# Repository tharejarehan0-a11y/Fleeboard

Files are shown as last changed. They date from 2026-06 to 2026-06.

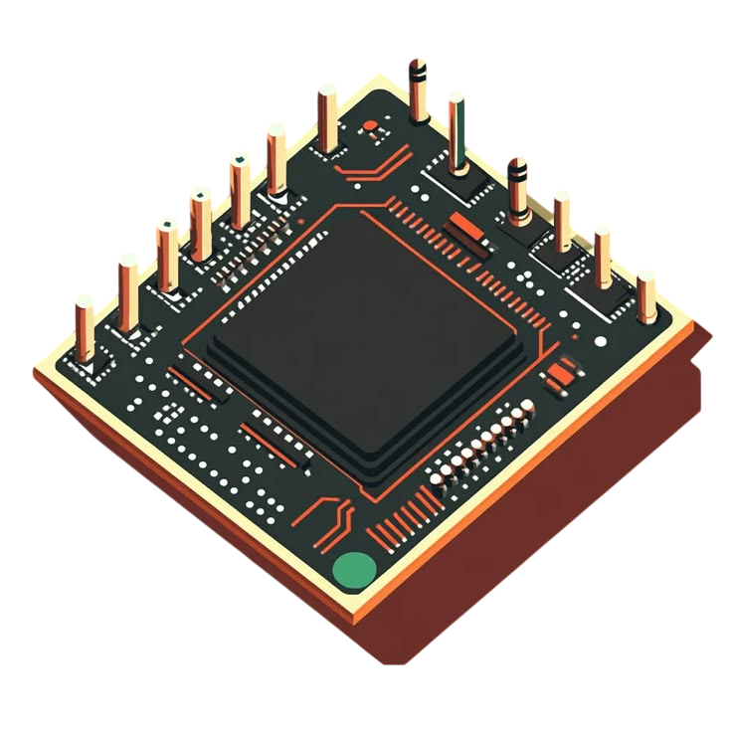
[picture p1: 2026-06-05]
Media/soc-Photoroom.png

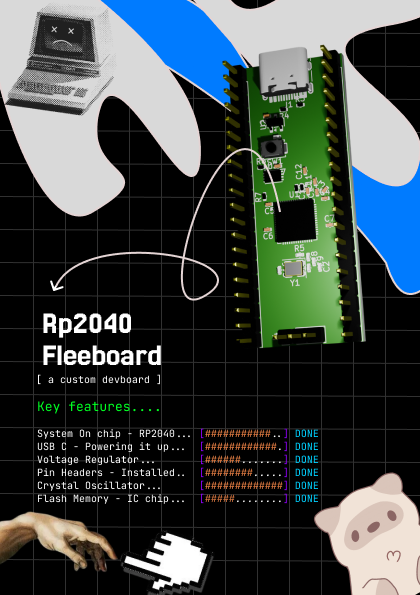
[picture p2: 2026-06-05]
Media/Zine.png

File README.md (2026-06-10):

# Fleeboard
<p align="center">
  
</p>

https://github.com/user-attachments/assets/660d7121-47da-4f55-9c74-c2678141ec92

card-Photoroom

# Why did i create this
I wanted a good starter project into a little more hardware and found the rp2040 soc with which i could design my own custom devboard but it's a little different as it has it's pin headers upwards thus is the name **FlipBoard** .The only difference between this and other devboards is the pinheaders . It's not something that could benefit people a lot but is just a experiment of going unconventional and seeing how it affects the board 

# Schematics
I started with the schematics and found out about the four main components of it the soc RP2040 , The memory , The Crystal Oscillator , USB-C Connector and the voltage regulator and the pin headers 

this is how u will be able to create this you add the rp2040 and add all the decoupling capcitors to the +3v3 and the +1v1 pins and then you add the crystal oscillator and attach it to the XIN and XOUT pins and add capcitors for reducing the noise and precise vibrations then you add the memory to it and attach the pins as the SPI Model says and attach the pin to the SPI pins of the memory and then you add the usb c connector and you go with the voltage regulator so as to reduce the current from +5v to +3v3 



# PCB <br>

**Footprints** <br>

Then while routing u use the footprints <br>
1. Memory - Winbond_USON-8-1EP_3x2mm_P0.5mm_EP0.2x1.6mm <br>
2. Voltage regulator - SOT-23 <br>
3. SOC - QFN-56-1EP_7x7mm_P0.4mm_EP3.2x3.2mm <br>
4. Crystal Oscillator - Crystal_SMD_3225-4Pin_3.2x2.5mm <br>
5. Capacitors - C_0402_1005Metric <br>
6. Resistors - R_0402_1005Metric <br>
7. Push Button - SW_Push_SPST_NO_Alps_SKRK <br>
8. USB - C - USB_C_Receptacle_HRO_TYPE-C-31-M-12 < br>
9. Pin Header Bottom - PinHeader_1x03_P2.54mm_Vertical <br>
10. Pin Headers ( Sides ) - PinHeader_1x20_P2.54mm_Vertical <br>

Screenshot 2026-06-05 at 6 58 44 AM
<br>

# Firmware

Screenshot 2026-06-11 at 5 20 55 AM

Then i wrote the firmware for blinking a led light so that the board can be tested with the code and its in c testing the gpio 25 as it is pin that will help you light up a led

The file is led.c in firmware folder for testing

# BOM <br>
**Sidenote for reviewers**
_(There is a chance that ktron.in does not accept the hcb money if it happens then i will pay my self)_

# Bill of Materials (BOM)

| Component | Footprint | Qty | Value | Price | Supplier | Link |
|---|---|-----|---|---|---|---|
| Capacitors | 0402 | 13 | 100nF | ₹34.84 | Robu | [GRM155R71C104JA88D](https://robu.in/product/grm155r71c104ja88d-murata-electronics-16v-100nf-x7r-%c2%b15-0402-multilayer-ceramic-capacitors-mlcc-smd-smt-rohs/) |
| Capacitors | 0402 | 2 | 10µF | ₹27.00 | Robu | [CC0402MRX5R5BB106](https://robu.in/product/cc0402mrx5r5bb106-yageo-cap-smd-mlcc-10-%c2%b5f-6-3-v-0402-1005-metric-20-x5r-cc-series/) |
| Capacitors | 0402 | 2 | 33pF | ₹12.00 | Robu | [GRM1555C2A330JA01D](https://robu.in/product/grm1555c2a330ja01d-murata-electronics-100v-33pf-null-%c2%b15-0402-multilayer-ceramic-capacitors-mlcc-smd-smt-rohs/) |
| USB-C port | USB_C_Receptacle_HRO_TYPE-C-31-M-12 | 1 | USB_C_Receptacle_USB2.0_14P | ₹54.00 | Robu | [TYPE-C-31-M-22](https://robu.in/product/type-c-31-m-22-hroparts-5a-1-surface-mount-right-angle-16p-female-30%e2%84%8385%e2%84%83-type-c-smd-usb-connectors-rohs/) |
| Pin headers | PinHeader_1x20_P2.54mm_Vertical | 2 | Conn_01x20 | ₹28.00 | Robu | [Pin Header](https://robu.in/product/1-month-warranty-898/) |
| Pin headers | PinHeader_1x03_P2.54mm_Vertical | 1 | Conn_01x03 | ₹11.97 | Robu | [Pin Header](https://robu.in/product/ph2-54-01-08pzd-xunpu-straight-policy-2-5mm-8p-6mm-40%e2%84%83105%e2%84%83-3mm-2-54mm-black-brass-single-row-1x8p-pluginp2-54mm-pin-headers-r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) |
| Resistors | 0402 | 2 | 27Ω | ₹10.26 | Robu | [AC0402JR-0727RL](https://robu.in/product/ac0402jr-0727rl-yageo-res-thick-film-0402-27-ohm-5-0-063w1-16w-%c2%b1100ppm-c-pad-smd-t-r-automotive-aec-q200/) |
| Resistors | 0402 | 2 | 5.1kΩ | ₹11.52 | Robu | [CRCW04025K10FKEDC](https://robu.in/product/crcw04025k10fkedc-vishay-smd-chip-resistor-5-1-kohm-%c2%b1-1-63-mw-0402-1005-metric-thick-film-general-purpose/) |
| Resistors | 0402 | 2 | 1kΩ | ₹11.67 | Robu | [RT1206FRE071KL](https://robu.in/product/rt1206fre071kl-yageo-smd-chip-resistor1-kohm%c2%b1-1250-mw1206-3216-metricthin-film/) |
| Resistors | 0402 | 1 | 10kΩ | ₹10.14 | Robu | [AC0402FR-0710KL](https://robu.in/product/ac0402fr-0710kl-yageo-res-thick-film-0402-10k-ohm-1-0-063w1-16w-%c2%b1100ppm-c-pad-smd-t-r-automotive-aec-q200/) |
| SW_push button | SW_Push_SPST_NO_Alps_SKRK | 2 | Push Button | ₹354.00 | LionCircuits | [SKRKAHE020](https://www.lioncircuits.com/parts/SKRKAHE020) |
| SCU Brain | QFN-56-1EP_7x7mm_P0.4mm_EP3.2x3.2mm | 1 | RP2040 | ₹68.00 | Robocraze | [RP2040](https://robocraze.com/products/raspberry-pi-rp2040-microcontroller-ic-chip?variant=40531158040729) |
| voltage regulator | SOT-23 | 1 | MCP1700-3302E/TT | ₹78.00 | Robu | [MCP1700T-3302E/TT](https://robu.in/product/mcp1700t-3302e-tt-microchip-technology-3-3v-250ma-fixed-output-ldo-linear-voltage-regulator-3-pin-sot-23/) |
| Memory | Winbond_USON-8-1EP_3x2mm_P0.5mm_EP0.2x1.6mm | 1 | W25Q128JVS | ₹294.00 | Robu | [W25Q128JVSIQ](https://robu.in/product/w25q128jvsiq-winbond-electronics-serial-nor-flash-memory-dual-quad-spi-3v-128mbit-133mhz-8pin-soic/) |
| crystal oscillator | Crystal_SMD_3225-4Pin_3.2x2.5mm | 1 | 12MHz Crystal | ₹48.00 | Robu | [OT2JI-111-12M](https://robu.in/product/ot2ji-111-12m/) |
| N/A | Shipping&Taxes | N/A | N/A | ₹700+39$ | N/A | N/A |

## Estimated Total Cost

**≈ ₹1,900.00**

> Prices may vary over time and based on stock availability.

# Problems I Faced
I faced a lot of problems in this project i started with some differnt idea in my mind of building my own thing like a desktop companion and made the project to complicated for me and i tried to work it out a lot made it through the pcb but then it was js out of my league then i asked sam liu if i can change up my mind and do something about it or change the project completely so what i did i took the knowledge for the hardware fromt the blueprint guide credits to team that built that and did a little bit of changes to it and this fleeboard was invented

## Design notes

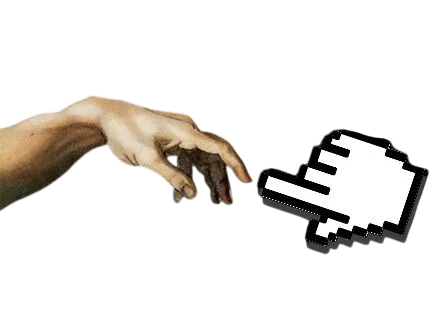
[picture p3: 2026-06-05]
Media/hand-Photoroom.png

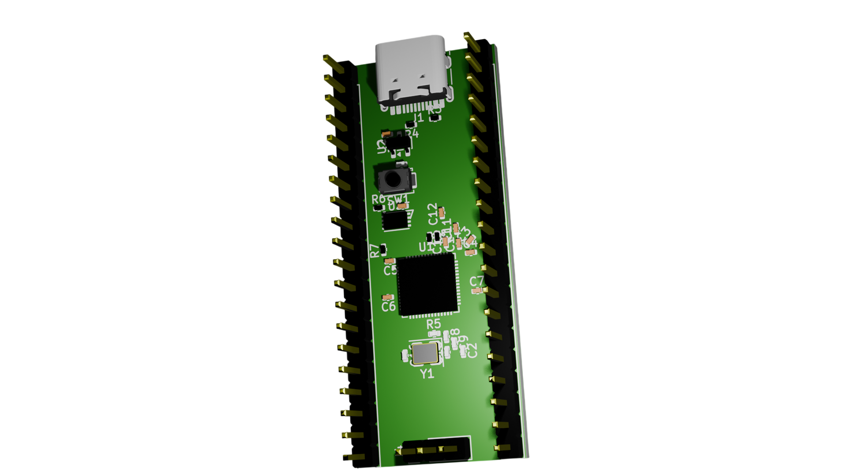
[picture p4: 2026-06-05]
Media/card-Photoroom.png

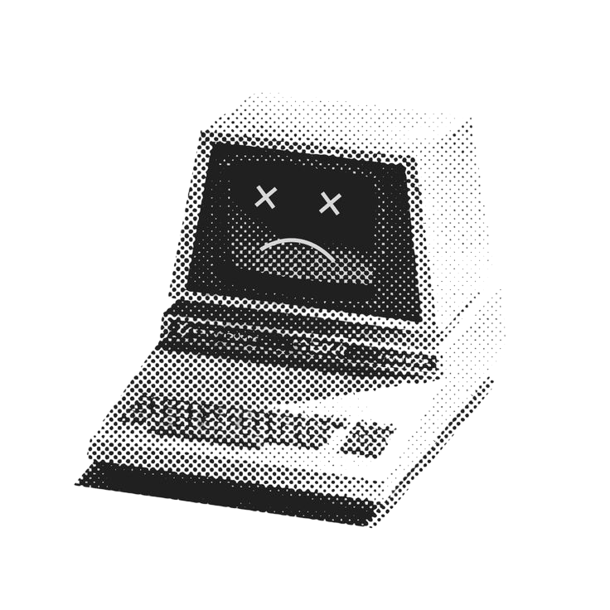
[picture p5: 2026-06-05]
Media/comp-Photoroom.png

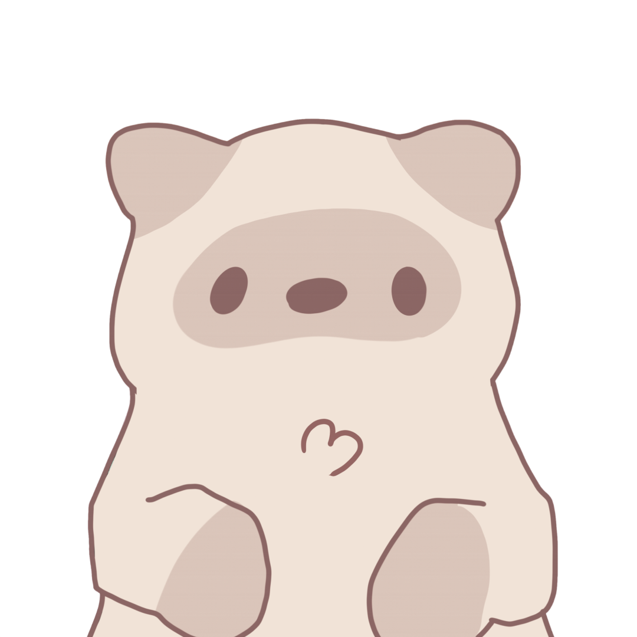
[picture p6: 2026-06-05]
Media/soup-Photoroom.png

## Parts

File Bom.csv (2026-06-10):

Designator | Footprint | Quantity | Value | Price | Website | Link
C1, C10, C11, C12, C17, C2, C3, C4, C5, C6, C7, C8, C9 | 402 | 13 | 100nF | ₹34.84 | Robu | https://robu.in/product/grm155r71c104ja88d-murata-electronics-16v-100nf-x7r-%c2%b15-0402-multilayer-ceramic-capacitors-mlcc-smd-smt-rohs/
C13, C14 | 402 | 3 | 10µF | ₹27.00 | Robu | https://robu.in/product/cc0402mrx5r5bb106-yageo-cap-smd-mlcc-10-%c2%b5f-6-3-v-0402-1005-metric-20-x5r-cc-series/
C15, C16 | 402 | 15 | 33pF | ₹12.00 | Robu | https://robu.in/product/grm1555c2a330ja01d-murata-electronics-100v-33pf-null-%c2%b15-0402-multilayer-ceramic-capacitors-mlcc-smd-smt-rohs/
J1 | USB_C_Receptacle_HRO_TYPE-C-31-M-12 | 1 | USB_C_Receptacle_USB2.0_14P | ₹54.00 | Robu | https://robu.in/product/type-c-31-m-22-hroparts-5a-1-surface-mount-right-angle-16p-female-30%e2%84%8385%e2%84%83-type-c-smd-usb-connectors-rohs/
J2, J3 | PinHeader_1x20_P2.54mm_Vertical | 2 | Conn_01x20 | ₹28.00 | Robu | https://robu.in/product/1-month-warranty-898/
J4 | PinHeader_1x03_P2.54mm_Vertical | 1 | Conn_01x03 | ₹11.97 | Robu | https://robu.in/product/ph2-54-01-08pzd-xunpu-straight-policy-2-5mm-8p-6mm-40%e2%84%83105%e2%84%83-3mm-2-54mm-black-brass-single-row-1x8p-pluginp2-54mm-pin-he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
R1, R2 | 402 | 27 | 27 | ₹10.26 | Robu | https://robu.in/product/ac0402jr-0727rl-yageo-res-thick-film-0402-27-ohm-5-0-063w1-16w-%c2%b1100ppm-c-pad-smd-t-r-automotive-aec-q200/
R3, R4 | 402 | 8 | 5.1K | ₹11.52 | Robu | https://robu.in/product/crcw04025k10fkedc-vishay-smd-chip-resistor-5-1-kohm-%c2%b1-1-63-mw-0402-1005-metric-thick-film-general-purpose/
R5, R6 | 402 | 3 | 1K | ₹11.67 | Robu | https://robu.in/product/rt1206fre071kl-yageo-smd-chip-resistor1-kohm%c2%b1-1250-mw1206-3216-metricthin-film/
R7 | 402 | 26 | 10K | ₹10.14 | Robu | https://robu.in/product/ac0402fr-0710kl-yageo-res-thick-film-0402-10k-ohm-1-0-063w1-16w-%c2%b1100ppm-c-pad-smd-t-r-automotive-aec-q200/
SW1 | SW_Push_SPST_NO_Alps_SKRK | 2 | SW_Push | ₹354.00 | LionCircuits | https://www.lioncircuits.com/parts/SKRKAHE020
U1 | QFN-56-1EP_7x7mm_P0.4mm_EP3.2x3.2mm | 1 | RP2040 | ₹68.00 | Robocraze | https://robocraze.com/products/raspberry-pi-rp2040-microcontroller-ic-chip?variant=40531158040729
U2 | SOT-23 | 2 | MCP1700x-330xxTT | ₹78.00 | Robu | https://robu.in/product/mcp1700t-3302e-tt-microchip-technology-3-3v-250ma-fixed-output-ldo-linear-voltage-regulator-3-pin-sot-23/
U3 | Winbond_USON-8-1EP_3x2mm_P0.5mm_EP0.2x1.6mm | 1 | W25Q128JVS | ₹294.00 | Robu | https://robu.in/product/w25q128jvsiq-winbond-electronics-serial-nor-flash-memory-dual-quad-spi-3v-128mbit-133mhz-8pin-soic/
Y1 | Crystal_SMD_3225-4Pin_3.2x2.5mm | 1 | Crystal_GND24 | ₹48.00 | Robu | https://robu.in/product/ot2ji-111-12m/

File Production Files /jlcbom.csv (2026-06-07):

Designator | Footprint | Quantity | Value | LCSC Part #
C1, C10, C11, C12, C17, C2, C3, C4, C5, C6, C7, C8, C9 | 0402 | 13 | 100nF
C13, C14 | 0402 | 2 | 10µF
C15, C16 | 0402 | 2 | 33pF
J1 | USB_C_Receptacle_HRO_TYPE-C-31-M-12 | 1 | USB_C_Receptacle_USB2.0_14P
J2, J3 | PinHeader_1x20_P2.54mm_Vertical | 2 | Conn_01x20
J4 | PinHeader_1x03_P2.54mm_Vertical | 1 | Conn_01x03
R1, R2 | 0402 | 2 | 27
R3, R4 | 0402 | 2 | 5.1K
R5, R6 | 0402 | 2 | 1K
R7 | 0402 | 1 | 10K
SW1 | SW_Push_SPST_NO_Alps_SKRK | 1 | SW_Push
U1 | QFN-56-1EP_7x7mm_P0.4mm_EP3.2x3.2mm | 1 | RP2040
U2 | SOT-23 | 1 | MCP1700x-330xxTT
U3 | Winbond_USON-8-1EP_3x2mm_P0.5mm_EP0.2x1.6mm | 1 | W25Q128JVS
Y1 | Crystal_SMD_3225-4Pin_3.2x2.5mm | 1 | Crystal_GND24

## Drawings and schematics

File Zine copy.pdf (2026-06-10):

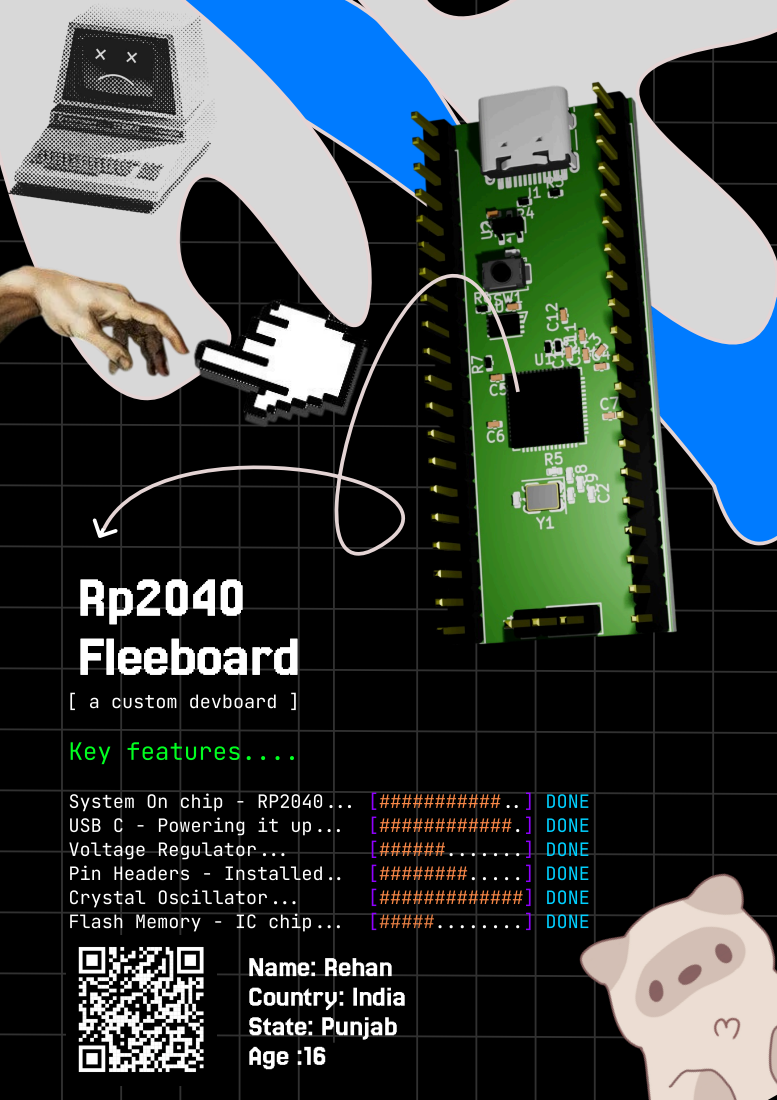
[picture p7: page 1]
Fleeboard; [ a custom; devboard ]; Key; features....; System On; chip -; DONE; USB C; Powering it up...; Voltage Regulator...; Pin Headers -; Installed..; Crystal Oscillator...; Flash; Memory -; IC chip...; Name: Rehan; Country: India; State: Punjab; Age

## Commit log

2026-06-05 Revise README for Flipboard project
    Updated project description and added schematics and PCB details.
2026-06-07 some updates
    [bom.csv, card.csv, designators.csv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]
2026-06-07 Add BOM section to README
2026-06-08 Update README with BOM details
    Added a table listing components with quantities and prices for BOM.
2026-06-10 Revise BOM section with detailed component list
    Updated the Bill of Materials (BOM) section with detailed component information, including designators, footprints, quantities, values, prices, suppliers, and links.
2026-06-10 Update BOM table headers and component entries
2026-06-10 Update README with firmware information for LED testing
    Added firmware section with details about LED testing code.
